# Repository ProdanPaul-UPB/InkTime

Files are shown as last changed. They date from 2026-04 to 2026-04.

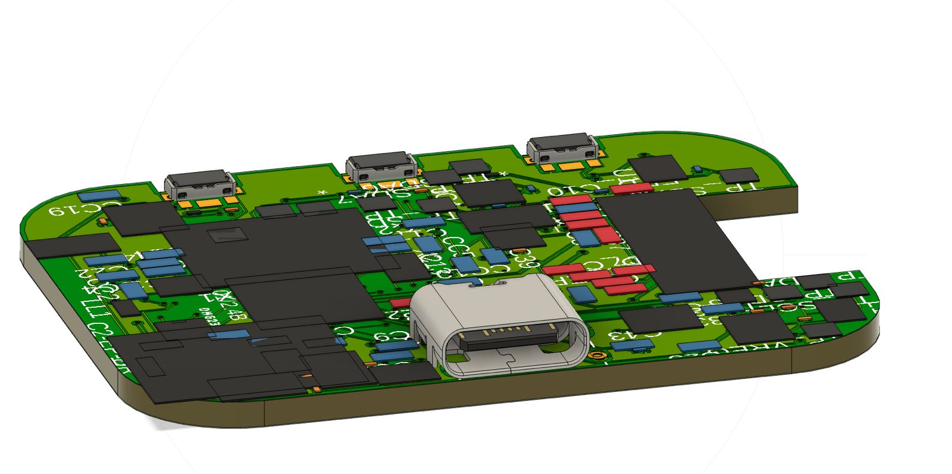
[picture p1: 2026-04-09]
Images/top_2.jpeg

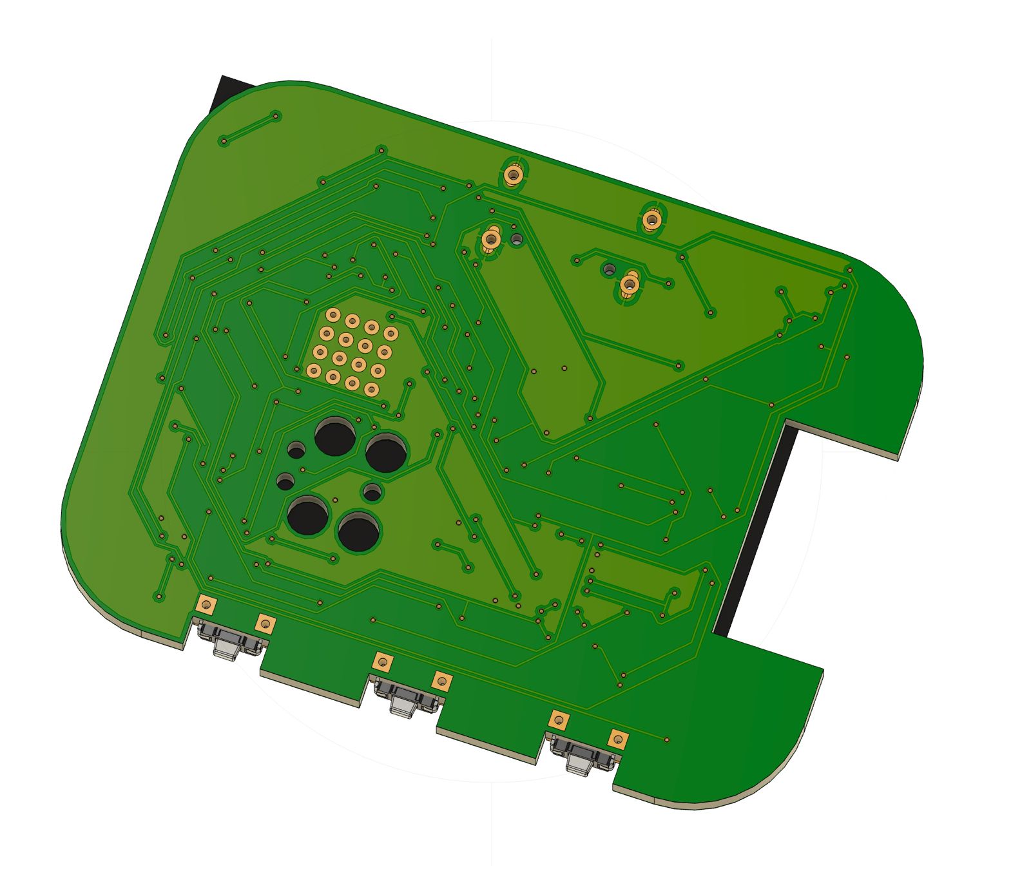
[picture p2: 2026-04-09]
Images/bottom.jpeg

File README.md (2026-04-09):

# InkTime — Open Source Smartwatch

InkTime is a low-power, open-source smartwatch built around the Nordic nRF52840 SoC and a 1.54" e-paper display. The goal was to design a device that can run for weeks on a single charge while still being useful as a daily wearable — no constant charging, no always-on backlight draining the battery.

This repo contains the full hardware design: schematic, PCB layout, manufacturing files, and the complete 3D assembly.

---

## Block Diagram

```
                        ┌─────────────────────────────────────────┐
                        │            nRF52840 (U1)                │
  USB-C (J4) ──► ESD ──►│ USB D+/D-          SPI ──────────────► │──► EPD Display (J1)
       │        (D3)    │                                         │    (Waveshare 1.54")
       │                │ I2C ──────────────────────────────────► │──► BMA423 IMU (IC3)
       ▼                │                   ├──────────────────► │──► MAX17048 Fuel Gauge (U3)
  BQ25180 (IC1) ───────►│ VBUS sense         └──────────────────► │──► DRV2605 Haptic (IC2)
  LiPo Charger          │                                         │
       │                │ GPIO ──────────────────────────────────►│──► SW_UP / SW_ENT / SW_DN
       ▼                │                                         │
  AKYGA LP502030        │ RF ────────────────────────────────────►│──► Matching Network
  3.7V / 250mAh         │                                         │    └──► ANT1 (2.4GHz)
       │                │ SWD ───────────────────────────────────►│──► TC2030-IDC (J2)
       ▼                └─────────────────────────────────────────┘
  RT6160A (IC9)
  DC-DC → 3.3V ──────────────────────────────────────────────────► All 3.3V rails
```

---

## Bill of Materials

| Ref | Component | Value / Part | Package | Datasheet | JLC Parts |
|-----|---|---|---|---|---|
| U1 | Nordic nRF52840 | nRF52840-QIAA | QFN-73 | [Datasheet](https://infocenter.nordicsemi.com/pdf/nRF52840_PS_v1.7.pdf) | [JLC](https://jlcpcb.com/partdetail/NordicSemiconductor-nRF52840QIAA/C190794) |
| IC1 | TI BQ25180 | LiPo Charger | DSBGA-9 | [Datasheet](https://www.ti.com/lit/ds/symlink/bq25180.pdf) | [JLC](https://jlcpcb.com/parts/componentSearch?searchTxt=BQ25180) |
| IC9 | RT6160A | DC-DC Buck 3.3V | WSON-6 | [Datasheet](https://www.richtek.com/assets/product_file/RT6160A/DS6160A-00.pdf) | [JLC](https://jlcpcb.com/parts/componentSearch?searchTxt=RT6160A) |
| U3 | MAX17048G+T10 | Fuel Gauge | SOT-23-6 | [Datasheet](https://www.analog.com/media/en/technical-documentation/data-sheets/MAX17048-MAX17049.pdf) | [JLC](https://jlcpcb.com/parts/componentSearch?searchTxt=MAX17048) |
| IC3 | BMA423 | Accelerometer | LGA-12 | [Datasheet](https://www.bosch-sensortec.com/media/boschsensortec/downloads/datasheets/bst-bma423-ds000.pdf) | [JLC](https://jlcpcb.com/parts/componentSearch?searchTxt=BMA423) |
| IC2 | DRV2605YZFR | Haptic Driver | DSBGA-12 | [Datasheet](https://www.ti.com/lit/ds/symlink/drv2605.pdf) | [JLC](https://jlcpcb.com/parts/componentSearch?searchTxt=DRV2605) |
| D3 | USBLC6-2SC6Y | USB ESD | SOT-363 | [Datasheet](https://www.st.com/resource/en/datasheet/usblc6-2.pdf) | [JLC](https://jlcpcb.com/parts/componentSearch?searchTxt=USBLC6-2SC6Y) |
| J4 | KH-TYPE-C-16P | USB-C Receptacle | SMD | — | [JLC](https://jlcpcb.com/parts/componentSearch?searchTxt=TYPE-C-16P) |
| J1 | Molex 503480-2400 | 24-pin FPC | SMD | [Datasheet](https://www.molex.com/en-us/products/part-detail/503480-2400) | [JLC](https://jlcpcb.com/parts/componentSearch?searchTxt=503480-2400) |
| J2 | TC2030-IDC | SWD Connector | THT | [Datasheet](https://www.tag-connect.com/product/tc2030-idc-nl) | — |
| ANT1 | 2450AT18B100E | 2.4GHz Antenna | SMD | [Datasheet](https://www.johansontechnology.com/datasheets/2450AT18B100E/2450AT18B100E.pdf) | [JLC](https://jlcpcb.com/parts/componentSearch?searchTxt=2450AT18B100E) |
| X1 | 32MHz Crystal | HFXO | SMD | — | [JLC](https://jlcpcb.com/parts/componentSearch?searchTxt=32MHz+crystal) |
| X2 | 32.768kHz Crystal | LFXO | SMD | — | [JLC](https://jlcpcb.com/parts/componentSearch?searchTxt=32.768kHz+crystal) |
| SW1-3 | EVP-AKE31A | Tactile Button | SMD | [Datasheet](https://industrial.panasonic.com/cdbs/www-data/pdf/ATV0000/ATV0000CE5.pdf) | [JLC](https://jlcpcb.com/parts/componentSearch?searchTxt=EVP-AKE31A) |
| — | AKYGA LP502030 | 3.7V / 250mAh LiPo | — | [Datasheet](https://www.tme.eu/Document/b9e12bf26ad0ba929a22ab5d58f022cd/AKY0106.pdf) | External |
| — | Waveshare WSH-12561 | 1.54" EPD Display | FPC-24 | [Datasheet](https://www.tme.eu/Document/0ca57a8ffbcd57b5bca53252eb9d6ec3/WSH-12561.pdf) | External |
| — | DFRobot FIT0774 | Vibration Motor | Coin 10×2.7mm | [Product page](https://www.tme.eu/ro/details/df-fit0774/motoare-dc/dfrobot/fit0774/) | External |
| Q3 | DMG2305UX | P-MOSFET | SOT-523 | [Datasheet](https://www.diodes.com/assets/Datasheets/DMG2305UX.pdf) | [JLC](https://jlcpcb.com/parts/componentSearch?searchTxt=DMG2305UX) |
| Q4 | SI1308EDL | N-MOSFET | SC-70 | [Datasheet](https://www.vishay.com/docs/73217/si1308edl.pdf) | [JLC](https://jlcpcb.com/parts/componentSearch?searchTxt=SI1308EDL) |
| L5 | 68µH Inductor | EPD Boost | 0402 | — | [JLC](https://jlcpcb.com/parts/componentSearch?searchTxt=68uH+0402) |
| L1 | 3.9nH Inductor | RF Matching | 0402 | — | [JLC](https://jlcpcb.com/parts/componentSearch?searchTxt=3.9nH+0402) |
| L2 | 15nH Inductor | RF Matching | 0402 | — | [JLC](https://jlcpcb.com/parts/componentSearch?searchTxt=15nH+0402) |
| L7 | 4.7µH Inductor | DC-DC Switching | 0402 | — | [JLC](https://jlcpcb.com/parts/componentSearch?searchTxt=4.7uH+0402) |
| R9 | 10kΩ | TS/MR Pull-down | 0201 | — | [JLC](https://jlcpcb.com/parts/componentSearch?searchTxt=10k+0201) |
| Various C | 100nF / 1µF / 10µF / 22µF | Decoupling | 0201 / 0402 | — | [JLC](https://jlcpcb.com/parts/componentSearch?searchTxt=100nF+0201) |

---

## Hardware Description

### Power Path

Power enters through the USB-C connector (J4). The BQ25180 charger (IC1) handles incoming VBUS and takes care of charging the LiPo battery safely — it supports up to 1A charge current with I²C-configurable parameters. The RT6160A (IC9) is a synchronous buck DC-DC converter that takes the battery voltage (3.0–4.2V) and steps it down to a clean 3.3V rail used by everything else on the board. The MAX17048 fuel gauge (U3) sits on the I²C bus and reports state of charge to the MCU so the watch can display battery percentage without the MCU having to do any ADC math itself.

The battery (AKYGA LP502030) is soldered directly to two test pads on the board rather than using a JST connector — this saves ~2mm of vertical height which matters a lot inside a watch case.

### Microcontroller

The nRF52840 (U1) is the brain of the device. It's a Cortex-M4F running at 64MHz with built-in Bluetooth 5.0 and a hardware USB controller. We used the QFN-73 package which has a 5×5mm exposed thermal pad underneath — there are thermal vias going through to the bottom GND plane to help with heat dissipation. The chip runs off the 3.3V rail and has 13 decoupling capacitors placed in a ring around its pads, as close to the power pins as the 2.54mm grid allows.

### Display Interface

The 1.54" e-paper display (Waveshare WSH-12561) connects through a 24-pin FPC connector (J1, Molex 503480-2400) on the left edge of the board. The EPD uses a 4-wire SPI interface plus three control lines (DC, RST, BUSY). The display only draws current during refresh — in static mode it consumes essentially nothing, which is the main reason e-paper was chosen for a watch that's supposed to last weeks.

Driving an EPD requires specific voltages that 3.3V alone can't provide. The EPD drive circuit uses a boost converter (Q4 N-MOSFET + L5 68µH inductor + D2 Schottky rectifier) to generate the higher voltages the display panel needs for VCOM and VDD. Q3 is a P-MOSFET power switch that the MCU uses to completely cut power to the display when it doesn't need it.

### Inertial Measurement Unit

The BMA423 (IC3) is a 6-axis IMU that handles step counting, activity recognition, and wrist-tilt detection (to wake the display when the user raises their wrist). It communicates over I²C and has its own interrupt output connected to a GPIO on the nRF52840 so it can wake the MCU from deep sleep without the MCU polling.

### Haptic Feedback

The DRV2605 (IC2) is a haptic driver that can drive both ERM (eccentric rotating mass) and LRA (linear resonant actuator) motors. It connects over I²C and has a library of pre-programmed waveforms built into its ROM, so the MCU just writes an effect number and the chip handles the timing. The FIT0774 vibration motor is a 10×2.7mm coin ERM motor that sits in the corner of the case behind the PCB.

### Bluetooth / RF

The nRF52840's built-in 2.4GHz radio connects to a chip antenna (Johanson 2450AT18B100E) through a pi-type matching network made of two series inductors (L1 3.9nH, L2 15nH) and two shunt capacitors (C3, C5 each 1pF). The antenna is placed at the edge of the PCB with a keepout zone below it — no copper planes or signal traces run under the antenna. Via stitching connects the top and bottom GND planes around the RF area to prevent ground loops from affecting the antenna's radiation pattern.

### USB and ESD Protection

The USBLC6-2SC6Y (D3) is a dual-channel TVS diode array placed between the USB-C connector and the nRF52840's USB pins. It clamps any ESD spikes from the connector before they can reach the MCU. The two CC pull-down resistors (5.1kΩ each) on CC1 and CC2 tell the USB host that this is a UFP (upstream facing port) device drawing up to 500mA.

### Debug Interface

The TC2030-IDC (J2) is a Tag-Connect 2×5 pogo-pin footprint for SWD debugging. It brings out SWDIO, SWDCLK, SWO, and RESET so a J-Link or similar debugger can program and debug the nRF52840 without needing a soldered header. Several test pads scattered around the board (labeled in silkscreen) expose the main power rails and I²C/SPI signals for probing during bring-up.

---

## nRF52840 Pin Mapping

| Pin | Signal | Connected To | Notes |
|-----|---|---|---|
| P0.06 | SDA | BMA423, MAX17048, DRV2605, BQ25180 | Shared I²C data |
| P0.08 | SCL | BMA423, MAX17048, DRV2605, BQ25180 | Shared I²C clock |
| P0.11 | MOSI | EPD Display (J1) | SPI data to display |
| P0.12 | MISO | EPD Display (J1) | SPI data from display |
| P0.13 | SCK | EPD Display (J1) | SPI clock |
| P0.14 | CS_EPD | EPD Display (J1) | SPI chip select |
| P0.15 | DC_EPD | EPD Display (J1) | Data/Command select |
| P0.16 | RST_EPD | EPD Display (J1) | Display reset |
| P0.17 | BUSY_EPD | EPD Display (J1) | Display busy indicator |
| P0.02 | SW_UP | SW1 (Up button) | Active low, internal pull-up |
| P0.03 | SW_ENT | SW2 (Enter button) | Active low, internal pull-up |
| P0.04 | SW_DN | SW3 (Down button) | Active low, internal pull-up |
| P0.29 | INT_IMU | BMA423 (IC3) | Interrupt from IMU |
| P0.30 | EN_EPD | Q3 gate | EPD power switch enable |
| P0.31 | EN_HAP | DRV2605 IN/TRIG | Haptic trigger signal |
| P0.20 | D+ | USBLC6 → USB-C | USB data positive |
| P0.22 | D− | USBLC6 → USB-C | USB data negative |
| SWDIO | SWDIO | TC2030-IDC (J2) | SWD debug interface |
| SWDCLK | SWDCLK | TC2030-IDC (J2) | SWD debug clock |
| P0.18 | RESET | TC2030-IDC (J2) | Hardware reset |
| XC1/XC2 | HFXO | X1 (32MHz) | High-frequency crystal oscillator |
| XL1/XL2 | LFXO | X2 (32.768kHz) | Low-frequency crystal for RTC |

The I²C bus is shared between four ICs — the BMA423, MAX17048, DRV2605, and BQ25180. Each has a different I²C address so there are no conflicts. SCL runs at 400kHz (fast mode).

---

## Power Consumption (estimated)

| Mode | Current draw |
|---|---|
| Deep sleep (display static, BLE off) | ~10–15 µA |
| Active (BLE advertising, IMU polling) | ~3–5 mA |
| Display refresh (EPD update) | ~20–30 mA for ~2s |
| USB charging | up to 250mA (BQ25180 configured) |

With the 250mAh battery and an estimated average current of ~0.5mA (mostly in deep sleep, occasional display updates and BLE), the target runtime is around 3–4 weeks between charges.

---

## PCB Details

- **Board dimensions:** 45.72mm × 34.29mm
- **Layers:** 2 (Top + Bottom)
- **Thickness:** 1.0mm
- **Surface finish:** HASL or ENIG
- **Min trace width:** 0.15mm (signals), 0.3mm (power)
- **Via drill:** 0.3mm min
- **GND planes:** Both TOP and BOTTOM layers, connected via stitching vias
- **Stackup:** Signal + GND pour (TOP) / GND pour + Signal (BOTTOM)
- **Antenna keepout:** No copper or signals under ANT1

All components are on the TOP layer only.

---

## Known Issues and Design Decisions

- **Board outline clearance errors:** The three tactile buttons (SW1–SW3) and the USB-C connector are intentionally positioned so they protrude into the board edge clearance zone. This is by design — they need to align with cutouts in the physical case and this placement was confirmed in the reference `.fbrd` layout from the course. These DRC errors are accepted and documented here.

- **Drill size errors:** Some via drill sizes fall slightly below the JLCPCB minimum due to the dense BGA escape routing under U1. These were the smallest vias needed to escape the MCU pads while still leaving clearance for adjacent traces. A PCB house that supports 0.2mm drills (like PCBWay) can manufacture these without issue. For JLCPCB specifically, these can be bumped to 0.3mm at the cost of routing one or two signals to alternate paths.

- **Battery connection:** The battery is soldered directly to TP_VBAT and TP_GND test pads instead of using the JST connector. This was intentional to reduce the height of the assembly so it fits inside the 1.0mm-thick PCB + battery stack constraint of the inktime_case enclosure.

- **EPD drive circuit:** The boost converter was designed around the voltage requirements in the WSH-12561 datasheet. The VCOM voltage is set via SJ1 — the solder jumper selects between direct GND and a resistor-divided reference, allowing adjustment during bring-up if the display contrast isn't right with the default value.

---

## Repository Structure

```
Hardware/
├── inktime.sch          — Schematic (Fusion 360 / EAGLE format)
├── inktime.brd          — PCB board file
└── inktime_schematic.pdf
Manufacturing/
├── gerbers.zip
├── inktime.bom
└── inktime.cpl
Mechanical/
├── inktime_assembly_exploded.step
└── inktime_complete.f3z
Images/
└── (PCB renders and assembly photos)
LICENSE
README.md
```

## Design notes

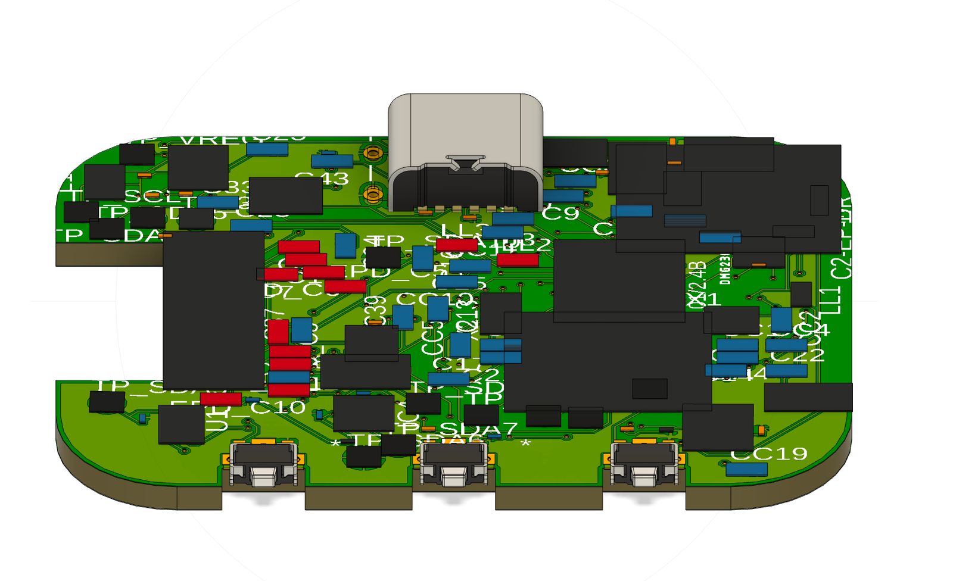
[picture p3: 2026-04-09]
Images/top_1.jpeg

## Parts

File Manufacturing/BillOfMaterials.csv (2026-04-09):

Qty | Value | Device | Package | Parts | Description | ARROW_PART_NUMBER | ARROW_PRICE-STOCK | AVAILABILITY | CHECK_PRICES | COPYRIGHT | DESCRIPTION | DIGI-KEY_PART_NUMBER_1 | DIGI-KEY_PART_NUMBER_2 | DIGI-KEY_PART_NUMBER_3 | HEIGHT | JLCPCB | MANUFACTURER_NAME | MANUFACTURER_PART_NUMBER | MF | MOUSER_PART_NUMBER | MOUSER_PRICE-STOCK | MP | PACKAGE | POPULARITY | PRICE | PURCHASE-URL | SNAPEDA_LINK | SPICEMODEL | SPICEPREFIX | TP_SIGNAL_NAME
1 | 0 | ESP32_C6_LIBRARY_7_JUMPER_SJ | ESP32_C6_LIBRARY_7_JUMPER_SJ | SJ1 | SMD solder JUMPER |  |  |  |  |  |  |  |  |  |  |  |  |  |  |  |  |  |  | 3
1 | 0.1uF | GRM011R60J152KE01L_1_GRM011R60J152KE01L | GRM011R60J152KE01L_1_0201 | C4 | Check availability
1 | 0.1uF | NORDIC_NRF_3_CAPACITOR_0402_M | NORDIC_NRF_3_RESC0402_M | C23 | Generic chip capacitor
1 | 0.1uF/50V | NORDIC_NRF_3_CAPACITOR_0402_M | NORDIC_NRF_3_RESC0402_M | EPD_C5 | Generic chip capacitor
4 | 100nF | NORDIC_NRF_3_CAPACITOR_0402_M | NORDIC_NRF_3_RESC0402_M | C7, C8, CC5, CC19 | Generic chip capacitor
2 | 100pF | NORDIC_NRF_3_CAPACITOR_0402_M | NORDIC_NRF_3_RESC0402_M | C12, CC11 | Generic chip capacitor
1 | 10K | CPF0201D7K68C1_CPF0201D7K68C1 | CPF0201D7K68C1_0201 | R9 | 7.68k 0201 Thin Film Surface Mount Fixed Resistor +/-0.5% 0.031W CPF0201D7K68C1
3 | 10uF | NORDIC_NRF_3_CAPACITOR_0402_M | NORDIC_NRF_3_RESC0402_M | C1-EP-DR, C24, C39 | Generic chip capacitor
1 | 10uH | NORDIC_NRF_2_INDUCTOR_0402_M | NORDIC_NRF_2_RESC0402_M | LL2 | Generic chip inductor
4 | 12pF | NORDIC_NRF_3_CAPACITOR_0402_M | NORDIC_NRF_3_RESC0402_M | C17, C18, CC1, CC2 | Generic chip capacitor
1 | 15uH | NORDIC_NRF_2_INDUCTOR_0402_M | NORDIC_NRF_2_RESC0402_M | LL3 | Generic chip inductor
2 | 1pF | NORDIC_NRF_3_CAPACITOR_0402_M | NORDIC_NRF_3_RESC0402_M | CC3, CC4 | Generic chip capacitor
1 | 1uF | GRM011R60J152KE01L_1_GRM011R60J152KE01L | GRM011R60J152KE01L_1_0201 | C3 | Check availability
3 | 1uF | NORDIC_NRF_3_CAPACITOR_0402_M | NORDIC_NRF_3_RESC0402_M | C15, C37, C38 | Generic chip capacitor
9 | 1uF/50V | NORDIC_NRF_3_CAPACITOR_0402_M | NORDIC_NRF_3_RESC0402_M | EPD_C1, EPD_C2, EPD_C6, EPD_C7, EPD_C8, EPD_C9, EPD_C10, EPD_C11, EPD_C12 | Generic chip capacitor
3 | 2025-10-22_07-23-44_LIBRARY_EVP-AKE31ASW_EVP-AKE31A_PAN | 2025-10-22_07-23-44_LIBRARY_EVP-AKE31ASW_EVP-AKE31A_PAN | 2025-10-22_07-23-44_LIBRARY_SW_EVP-AKE31A_PAN | SW1, SW2, SW3 |  |  |  |  |  | Copyright (C) 2025 Ultra Librarian. All rights reserved. |  | P123437TR-ND | P123437CT-ND | P123437DKR-ND |  |  | Panasonic | EVP-AKE31A
2 | 22uF | NORDIC_NRF_3_CAPACITOR_0402_M | NORDIC_NRF_3_RESC0402_M | C25, C33 | Generic chip capacitor
1 | 2450AT18B100E_2450AT18B100E | 2450AT18B100E_2450AT18B100E | 2450AT18B100E_ANTC3216X140N | ANT1 | Antennas 2.45GHz ANTENNA | 2450AT18B100E | https://www.arrow.com/en/products/2450at18b100e/johanson-dielectrics?utm_currency=USD&region=nac |  |  |  | Antennas 2.45GHz ANTENNA |  |  |  | 1.4mm |  | JOHANSON TECHNOLOGY | 2450AT18B100E |  | 609-2450AT18B100E | https://www.mouser.co.uk/ProductDetail/Johanson-Technology/2450AT18B100E?qs=yCnrNFeXz%252Bh5MFsFIXGZGA%3D%3D
1 | 3.9nH | NORDIC_NRF_2_INDUCTOR_0402_M | NORDIC_NRF_2_RESC0402_M | LL1 | Generic chip inductor
1 | 32.768KHz | NORDIC_NRF_1_XTAL_32KHZ | NORDIC_NRF_1_XTAL_3215_N | X2
1 | 32MHz | NORDIC_NRF_XTAL_32MHZ | NORDIC_NRF_BT-XTAL_2016_N | X1
5 | 4.7uF | NORDIC_NRF_3_CAPACITOR_0402_M | NORDIC_NRF_3_RESC0402_M | C6, C20, C21, C43, CC14 | Generic chip capacitor
1 | 4.7uF/25V | ESP32_C6_LIBRARY_1_ESP32_WROVER_EAGLE-LTSPICE_CC0402 | ESP32_C6_LIBRARY_1_ESP32_WROVER_EAGLE-LTSPICE_C0402 | C2-EP-DR | CAPACITOR, European symbol |  |  |  |  |  |  |  |  |  |  |  |  |  |  |  |  |  |  |  |  |  |  | NONE | C
1 | 47nF | NORDIC_NRF_3_CAPACITOR_0402_M | NORDIC_NRF_3_RESC0402_M | C16 | Generic chip capacitor
1 | 503480-2400_503480-2400 | 503480-2400_503480-2400 | 503480-2400_5034802400 | J2 | FFC & FPC Connectors 0.5mm FPC RA SMT Dual Contact 24Ckt |  |  |  |  |  | FFC & FPC Connectors 0.5mm FPC RA SMT Dual Contact 24Ckt |  |  |  | 1.87mm |  | Molex | 503480-2400 |  | 538-503480-2400 | https://www.mouser.co.uk/ProductDetail/Molex/503480-2400?qs=OAhjpuo3Vu7efIoxFh9AOw%3D%3D
1 | 820pF | NORDIC_NRF_3_CAPACITOR_0402_M | NORDIC_NRF_3_RESC0402_M | C9 | Generic chip capacitor
1 | BMA423_BMA423 | BMA423_BMA423 | BMA423_BMA423 | IC3 | Accelerometers Triaxial low-g 12bit Acceleration Sensor | BMA423 | https://www.arrow.com/en/products/bma423/bosch |  |  |  | Accelerometers Triaxial low-g 12bit Acceleration Sensor |  |  |  | 1mm |  | BOSCH | BMA423 |  | 262-BMA423 | https://www.mouser.co.uk/ProductDetail/Bosch-Sensortec/BMA423?qs=HXFqYaX1Q2xC%252BSgeGoX3mg%3D%3D
1 | BQ25180YBGR_BQ25180YBGR | BQ25180YBGR_BQ25180YBGR | BQ25180YBGR_BGA8C40P2X4_100X155X50 | IC1 | Charger IC Lithium Ion/Polymer, Lithium Iron Phosphate 8-DSBGA (1.6x1.1) | BQ25180YBGR | https://www.arrow.com/en/products/bq25180ybgr/texas-instruments?utm_currency=USD&region=nac |  |  |  | Charger IC Lithium Ion/Polymer | Lithium Iron Phosphate 8-DSBGA (1.6x1.1) |  |  |  | 0.5mm |  | Texas Instruments | BQ25180YBGR |  | 595-BQ25180YBGR | https://www.mouser.co.uk/ProductDetail/Texas-Instruments/BQ25180YBGR?qs=doiCPypUmgEWjAK%252BJAX6Tw%3D%3D
10 | CPF0201D7K68C1_CPF0201D7K68C1 | CPF0201D7K68C1_CPF0201D7K68C1 | CPF0201D7K68C1_0201 | R2, R3, R4, R5, R8, R11, R12, R13, R14, R15 | 7.68k 0201 Thin Film Surface Mount Fixed Resistor +/-0.5% 0.031W CPF0201D7K68C1
1 | DRV2605YZFR_DRV2605YZFR | DRV2605YZFR_DRV2605YZFR | DRV2605YZFR_BGA9C50P3X3_144X144X62 | IC4 | Haptic Driver for ERM/LRA with Built-In Library and Smart Loop Architecture | DRV2605YZFR | https://www.arrow.com/en/products/drv2605yzfr/texas-instruments?region=nac |  |  |  | Haptic Driver for ERM/LRA with Built-In Library and Smart Loop Architecture |  |  |  | 0.625mm |  | Texas Instruments | DRV2605YZFR
1 | ESP32_C6_LIBRARY_3_USBLC6-2SC6Y | ESP32_C6_LIBRARY_3_USBLC6-2SC6Y | ESP32_C6_LIBRARY_3_SOT95P280X145-6N | D4 | Low Cap. ESD Protection Auto SOT-23-6 STMicroelectronics USBLC6-2SC6Y, Dual Uni-Directional TVS Diode Array, 6-Pin SOT-23 |  |  | In Stock | https://www.snapeda.com/parts/USBLC6-2SC6Y/STMicroelectronics/view-part/?ref=eda |  | 17V Clamp 5A (8/20µs) Ipp Tvs Diode Surface Mount SOT-23-6 |  |  |  |  |  |  |  | STMicroelectronics |  |  | USBLC6-2SC6Y | SOT-23-6 STMicroelectronics |  | None |  | https://www.snapeda.com/parts/USBLC6-2SC6Y/STMicroelectronics/view-part/?ref=snap
3 | ESP32_C6_LIBRARY_5_MBR0530 | ESP32_C6_LIBRARY_5_MBR0530 | ESP32_C6_LIBRARY_5_SOD3716X135N | D1, D2, D3 | ON SEMICONDUCTOR - MBR0530 - DIODE, SCHOTTKY, 0.5A, 30V, SOD-123 |  |  | In Stock | https://www.snapeda.com/parts/MBR0530/Onsemi/view-part/?ref=eda |  | Diode Schottky 30 V 500mA Surface Mount SOD-123 |  |  |  |  |  |  |  | ON Semiconductor |  |  | MBR0530 | SOD-123-2 ON Semiconductor |  | None | https://www.snapeda.com/api/url_track_click_mouser/?unipart_id=179458&manufacturer=ON Semiconductor&part_name=MBR0530&search_term=None | https://www.snapeda.com/parts/MBR0530/Onsemi/view-part/?ref=snap
1 | ESP32_C6_LIBRARY_6_SI1308EDL-T1-GE3 | ESP32_C6_LIBRARY_6_SI1308EDL-T1-GE3 | ESP32_C6_LIBRARY_6_SOT65P210X110-3N | Q2 | MOSFET N-Ch 30V 1.5A TrenchFET SC70 Vishay Si1308EDL-T1-GE3 N-channel MOSFET Transistor, 1.5 A, 30 V, 3-Pin SC-70 |  |  | In Stock | https://www.snapeda.com/parts/SI1308EDL-T1-GE3/Vishay+Siliconix/view-part/?ref=eda |  | Si1308EDL-T1-GE3 N-channel MOSFET Transistor | 1.5 A | 30 V | 3-Pin SC-70 | Siliconix / Vishay SI1308EDL-T1-GE3 |  |  |  |  |  |  |  | Vishay Siliconix |  |  | SI1308EDL-T1-GE3 | SOT-323 Vishay Semiconductor |  | None | https://www.snapeda.com/api/url_track_click_mouser/?unipart_id=274603&manufacturer=Vishay Siliconix&part_name=SI1308EDL-T1-GE3&search_term=None | https://www.snapeda.com/parts/SI1308EDL-T1-GE3/Vishay+Siliconix/view-part/?ref=snap
1 | ESP32_C6_LIBRARY_MAX17048G+T10 | ESP32_C6_LIBRARY_MAX17048G+T10 | ESP32_C6_LIBRARY_SON50P200X200X80-9N | U1 | Check availability |  |  | In Stock | https://www.snapeda.com/parts/MAX17048G+T10/Analog+Devices/view-part/?ref=eda |  | 3µA 1-Cell/2-Cell Fuel Gauge with ModelGauge |  |  |  |  |  |  |  | Analog Devices |  |  | MAX17048G+T10 | TDFN-8 Maxim |  | None | https://www.snapeda.com/api/url_track_click_mouser/?unipart_id=329239&manufacturer=Analog Devices&part_name=MAX17048G+T10&search_term=None | https://www.snapeda.com/parts/MAX17048G+T10/Analog+Devices/view-part/?ref=snap
5 | GRM011R60J152KE01L_1_GRM011R60J152KE01L | GRM011R60J152KE01L_1_GRM011R60J152KE01L | GRM011R60J152KE01L_1_0201 | C2, C5, C10, C11, C42 | Check availability
14 | HECTOR_WATCH_1_TPTP20R | HECTOR_WATCH_1_TPTP20R | HECTOR_WATCH_1_TP20R | TP_3V3, TP_SCL, TP_SDA, TP_SDA1, TP_SDA2, TP_SDA3, TP_SDA4, TP_SDA5, TP_SDA6, TP_SDA7, TP_SDA8, TP_SDA9, TP_SDA10, TP_VREG | Test pad |  |  |  |  |  |  |  |  |  |  |  |  |  |  |  |  |  |  | 2
1 | KH-TYPE-C-16P_KH-TYPE-C-16P | KH-TYPE-C-16P_KH-TYPE-C-16P | KH-TYPE-C-16P_KINGHELM_KH-TYPE-C-16P | J3 | Check availability |  |  | Not in stock | https://www.snapeda.com/parts/KH-TYPE-C-16P/Kinghelm/view-part/?ref=eda |  |  |  |  |  |  |  |  |  | kinghelm |  |  | KH-TYPE-C-16P | None |  | None |  | https://www.snapeda.com/parts/KH-TYPE-C-16P/Kinghelm/view-part/?ref=snap
1 | MLP2016SR47MT0S1_FTC252012SR47MBCA | MLP2016SR47MT0S1_FTC252012SR47MBCA | MLP2016SR47MT0S1_INDC2016X100N | L1 | SMD / SMT Inductors (Coils), L=0.47?H, L x W x T : |  |  |  |  |  | SMD / SMT Inductors (Coils) | L=0.47?H | L x W x T : |  |  |  | 1mm | https://jlcpcb.com/partdetail/6763488-FTC252012SR47MBCA/C5832368 | TDK | FTC252012SR47MBCA
2 | N.C | NORDIC_NRF_3_CAPACITOR_0402_M | NORDIC_NRF_3_RESC0402_M | C13, CC10 | Generic chip capacitor
1 | NORDIC_NRF_4_NRF52840_QF | NORDIC_NRF_4_NRF52840_QF | NORDIC_NRF_4_AQFN50P700X700X85_HS-74N | P1.01/2.4B | nRF52840
1 | RT6160AWSC_RT6160AWSC | RT6160AWSC_RT6160AWSC | RT6160AWSC_BGA15C40P3X5_140X230X60 | IC2 | Buck-Boost Regulator Positive Output Step-Up/Step-Down I2C DC-DC Controller IC 15-WL-CSP (BSC) (1.4x2.3) |  |  |  |  |  | Buck-Boost Regulator Positive Output Step-Up/Step-Down I2C DC-DC Controller IC 15-WL-CSP (BSC) (1.4x2.3) |  |  |  | 0.6mm |  | RICHTEK | RT6160AWSC |  | 835-RT6160AWSC | https://www.mouser.co.uk/ProductDetail/Richtek/RT6160AWSC?qs=amGC7iS6iy%2FLd9PSoixZXQ%3D%3D

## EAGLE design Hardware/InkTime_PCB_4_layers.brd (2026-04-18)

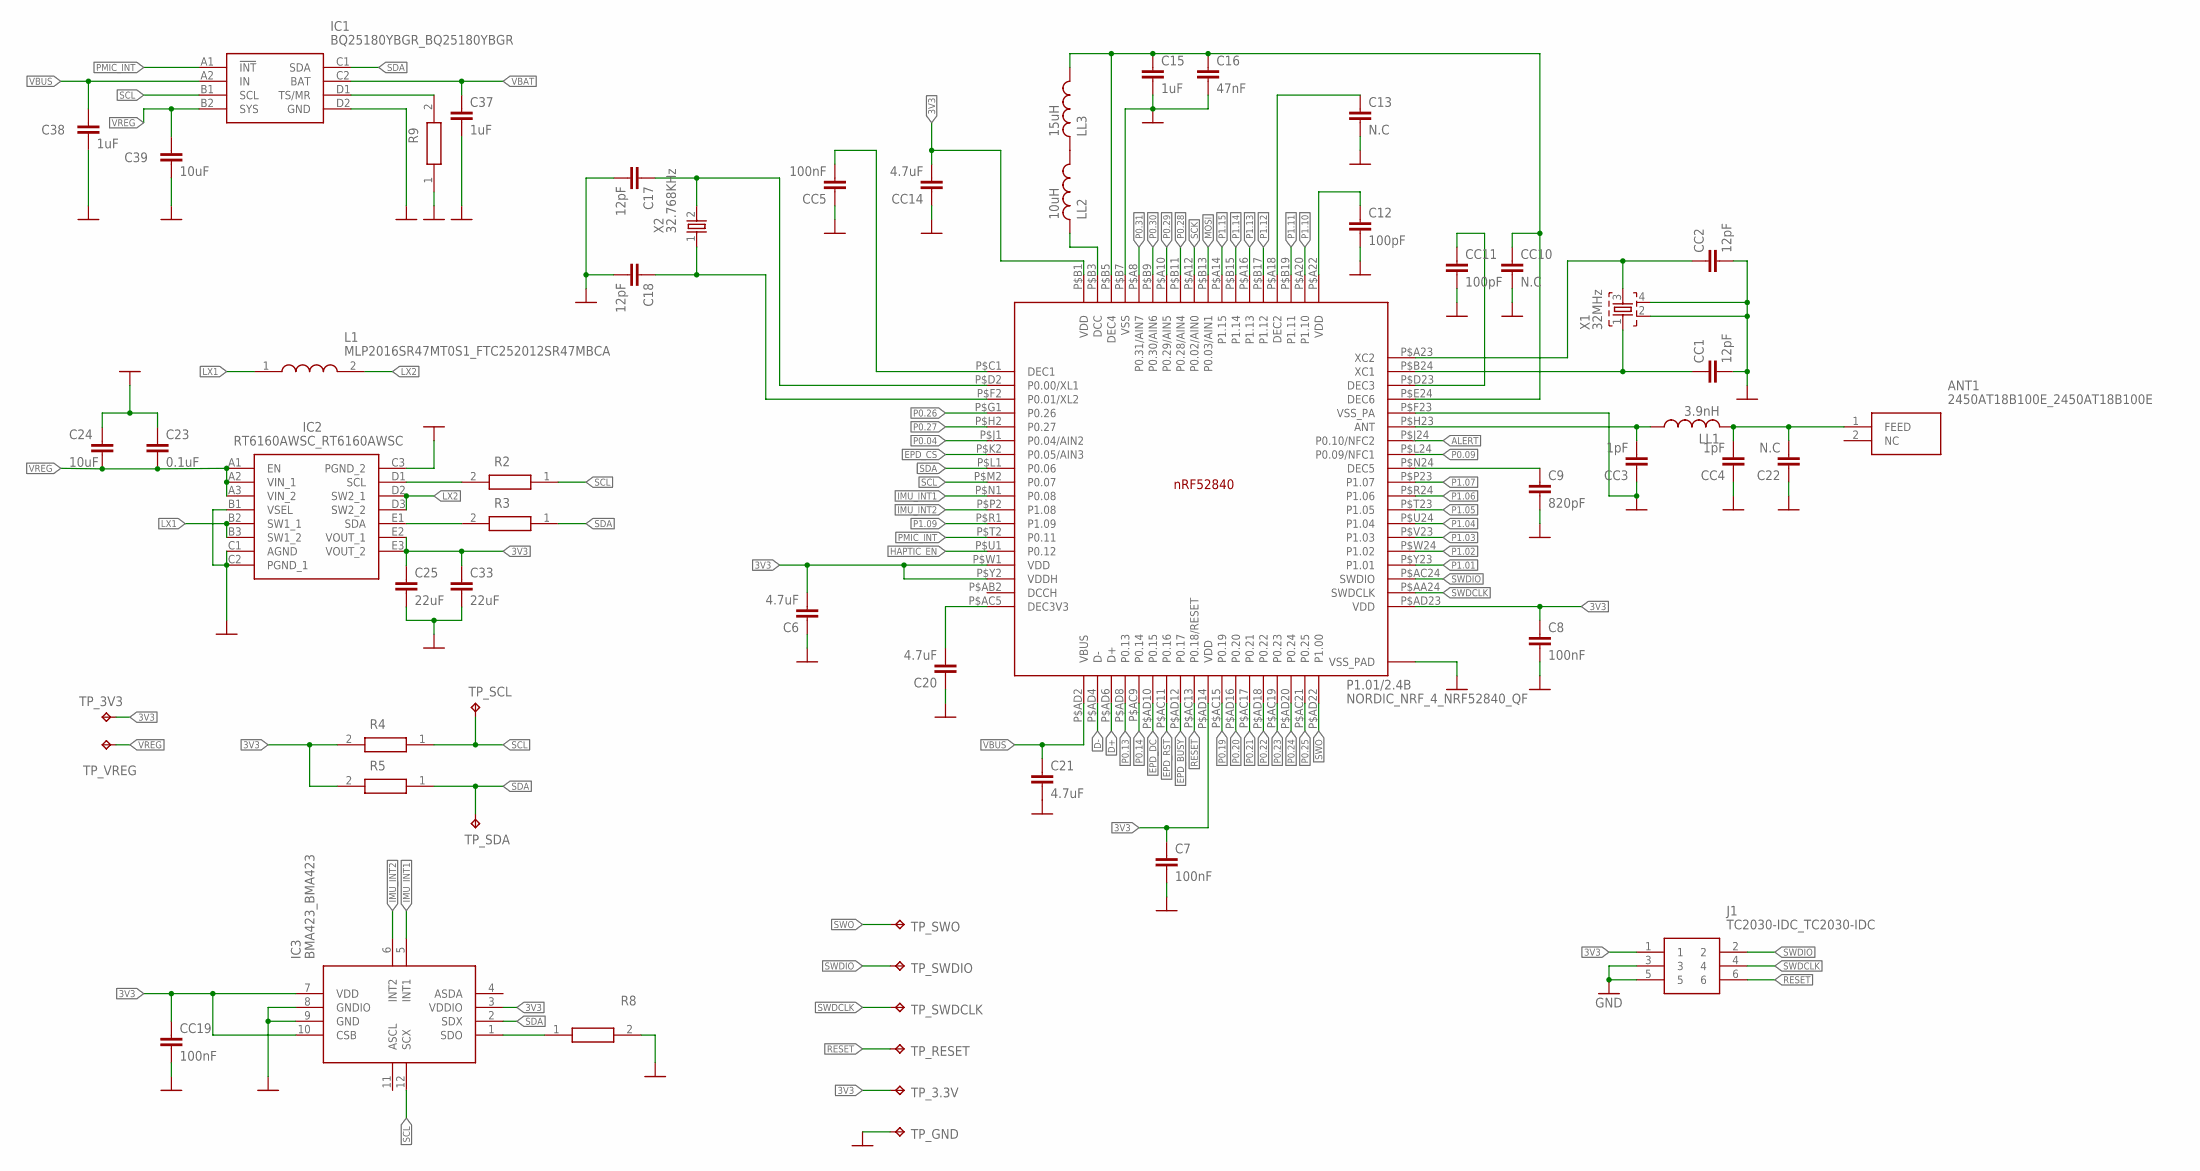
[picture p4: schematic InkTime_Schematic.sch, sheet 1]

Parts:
ANT1: 2450AT18B100E_2450AT18B100E; 2450AT18B100E_ANTC3216X140N
C6, C20, C21: 4.7uF; NORDIC_NRF_3_RESC0402_M
C7, C8: 100nF; NORDIC_NRF_3_RESC0402_M
C9: 820pF; NORDIC_NRF_3_RESC0402_M
C12: 100pF; NORDIC_NRF_3_RESC0402_M
C13, C22: N.C; NORDIC_NRF_3_RESC0402_M
C15, C37, C38: 1uF; NORDIC_NRF_3_RESC0402_M
C16: 47nF; NORDIC_NRF_3_RESC0402_M
C17, C18: 12pF; NORDIC_NRF_3_RESC0402_M
C23: 0.1uF; NORDIC_NRF_3_RESC0402_M
C24, C39: 10uF; NORDIC_NRF_3_RESC0402_M
C25, C33: 22uF; NORDIC_NRF_3_RESC0402_M
CC1, CC2: 12pF; NORDIC_NRF_3_RESC0402_M
CC3, CC4: 1pF; NORDIC_NRF_3_RESC0402_M
CC5, CC19: 100nF; NORDIC_NRF_3_RESC0402_M
CC10: N.C; NORDIC_NRF_3_RESC0402_M
CC11: 100pF; NORDIC_NRF_3_RESC0402_M
CC14: 4.7uF; NORDIC_NRF_3_RESC0402_M
IC1: BQ25180YBGR_BQ25180YBGR; BQ25180YBGR_BGA8C40P2X4_100X155X50
IC2: RT6160AWSC_RT6160AWSC; RT6160AWSC_BGA15C40P3X5_140X230X60
IC3: BMA423_BMA423
J1: TC2030-IDC_TC2030-IDC; TC2030-IDC_TC2030IDC
L1: MLP2016SR47MT0S1_FTC252012SR47MBCA; MLP2016SR47MT0S1_INDC2016X100N
LL1: 3.9nH; NORDIC_NRF_2_RESC0402_M
LL2: 10uH; NORDIC_NRF_2_RESC0402_M
LL3: 15uH; NORDIC_NRF_2_RESC0402_M
P1.01/2.4B: NORDIC_NRF_4_NRF52840_QF; NORDIC_NRF_4_AQFN50P700X700X85_HS-74N
R2, R3, R4, R5, R8: CPF0201D7K68C1_CPF0201D7K68C1; CPF0201D7K68C1_0201
R9: 10K; CPF0201D7K68C1_0201
TP_3.3V, TP_3V3: HECTOR_WATCH_1_TPTP20R; HECTOR_WATCH_1_TP20R
TP_GND: HECTOR_WATCH_1_TPTP20R; HECTOR_WATCH_1_TP20R
TP_RESET: HECTOR_WATCH_1_TPTP20R; HECTOR_WATCH_1_TP20R
TP_SCL: HECTOR_WATCH_1_TPTP20R; HECTOR_WATCH_1_TP20R
TP_SDA: HECTOR_WATCH_1_TPTP20R; HECTOR_WATCH_1_TP20R
TP_SWDCLK: HECTOR_WATCH_1_TPTP20R; HECTOR_WATCH_1_TP20R
TP_SWDIO: HECTOR_WATCH_1_TPTP20R; HECTOR_WATCH_1_TP20R
TP_SWO: HECTOR_WATCH_1_TPTP20R; HECTOR_WATCH_1_TP20R
TP_VREG: HECTOR_WATCH_1_TPTP20R; HECTOR_WATCH_1_TP20R
X1: 32MHz; NORDIC_NRF_BT-XTAL_2016_N
X2: 32.768KHz; NORDIC_NRF_1_XTAL_3215_N

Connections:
3V3: C6.2, C7.1, C8.1, C25.1, C33.1, CC14.2, CC19.1, IC2.E2 (VOUT_1), IC2.E3 (VOUT_2), IC3.3 (VDDIO), IC3.7 (VDD), IC3.10 (CSB), J1.1, P1.01/2.4B.P$AD14 (VDD), P1.01/2.4B.P$AD23 (VDD), P1.01/2.4B.P$B1 (VDD), P1.01/2.4B.P$W1 (VDD), P1.01/2.4B.P$Y2 (VDDH), R4.2, R5.2, TP_3.3V.TP, TP_3V3.TP; also elsewhere on the board
ALERT: P1.01/2.4B.P$J24 (P0.10/NFC2); also elsewhere on the board
D+: P1.01/2.4B.P$AD6 (D+); also elsewhere on the board
D-: P1.01/2.4B.P$AD4 (D-); also elsewhere on the board
EPD_BUSY: P1.01/2.4B.P$AD12 (P0.17); also elsewhere on the board
EPD_CS: P1.01/2.4B.P$K2 (P0.05/AIN3); also elsewhere on the board
EPD_DC: P1.01/2.4B.P$AD10 (P0.15); also elsewhere on the board
EPD_RST: P1.01/2.4B.P$AC11 (P0.16); also elsewhere on the board
GND: C6.1, C7.2, C8.2, C9.2, C12.2, C13.2, C15.2, C16.2, C17.2, C18.2, C20.1, C21.2, C22.1, C23.1, C24.1, C25.2, C33.2, C37.2, C38.2, C39.2, CC1.2, CC2.2, CC3.1, CC4.1, CC5.1, CC10.2, CC11.2, CC14.1, CC19.2, IC1.D2 (GND), IC2.B1 (VSEL), IC2.C1 (AGND), IC2.C2 (PGND_1), IC2.C3 (PGND_2), IC3.8 (GNDIO), IC3.9 (GND), J1.3, J1.5, P1.01/2.4B.P$74 (VSS_PAD), P1.01/2.4B.P$75 (VSS_PAD), P1.01/2.4B.P$76 (VSS_PAD), P1.01/2.4B.P$77 (VSS_PAD), P1.01/2.4B.P$78 (VSS_PAD), P1.01/2.4B.P$79 (VSS_PAD), P1.01/2.4B.P$80 (VSS_PAD), P1.01/2.4B.P$81 (VSS_PAD), P1.01/2.4B.P$82 (VSS_PAD), P1.01/2.4B.P$83 (VSS_PAD), P1.01/2.4B.P$84 (VSS_PAD), P1.01/2.4B.P$85 (VSS_PAD), P1.01/2.4B.P$86 (VSS_PAD), P1.01/2.4B.P$87 (VSS_PAD), P1.01/2.4B.P$88 (VSS_PAD), P1.01/2.4B.P$89 (VSS_PAD), P1.01/2.4B.P$90 (VSS_PAD), P1.01/2.4B.P$B7 (VSS), P1.01/2.4B.P$F23 (VSS_PA), R8.2, R9.1, TP_GND.TP, X1.2, X1.4; also elsewhere on the board
HAPTIC_EN: P1.01/2.4B.P$U1 (P0.12); also elsewhere on the board
IMU_INT1: IC3.5 (INT1), P1.01/2.4B.P$N1 (P0.08)
IMU_INT2: IC3.6 (INT2), P1.01/2.4B.P$P2 (P1.08)
LX1: IC2.B2 (SW1_1), IC2.B3 (SW1_2), L1.1
LX2: IC2.D2 (SW2_1), IC2.D3 (SW2_2), L1.2
MOSI: P1.01/2.4B.P$B13 (P0.03/AIN1); also elsewhere on the board
unnamed: IC1.D1 (TS/MR), R9.2
unnamed: C9.1, P1.01/2.4B.P$N24 (DEC5)
unnamed: CC3.2, LL1.1, P1.01/2.4B.P$H23 (ANT)
unnamed: IC2.D1 (SCL), R2.2
unnamed: IC2.E1 (SDA), R3.2
unnamed: C20.2, P1.01/2.4B.P$AC5 (DEC3V3)
unnamed: ANT1.1 (FEED), C22.2, CC4.2, LL1.2
unnamed: CC1.1, P1.01/2.4B.P$B24 (XC1), X1.1
unnamed: CC2.1, P1.01/2.4B.P$A23 (XC2), X1.3
unnamed: CC11.1, P1.01/2.4B.P$D23 (DEC3)
unnamed: C18.1, P1.01/2.4B.P$F2 (P0.01/XL2), X2.1
unnamed: C12.1, P1.01/2.4B.P$A22 (VDD)
unnamed: C13.1, P1.01/2.4B.P$A18 (DEC2)
unnamed: LL2.1, LL3.2
unnamed: LL2.2, P1.01/2.4B.P$B3 (DCC)
unnamed: C15.1, C16.1, CC10.1, LL3.1, P1.01/2.4B.P$B5 (DEC4), P1.01/2.4B.P$E24 (DEC6)
unnamed: C17.1, P1.01/2.4B.P$D2 (P0.00/XL1), X2.2
unnamed: IC3.1 (SDO), R8.1
unnamed: CC5.2, P1.01/2.4B.P$C1 (DEC1)
P0.04: P1.01/2.4B.P$J1 (P0.04/AIN2)
P0.09: P1.01/2.4B.P$L24 (P0.09/NFC1)
P0.13: P1.01/2.4B.P$AD8 (P0.13); also elsewhere on the board
P0.14: P1.01/2.4B.P$AC9 (P0.14); also elsewhere on the board
P0.19: P1.01/2.4B.P$AC15 (P0.19)
P0.20: P1.01/2.4B.P$AD16 (P0.20)
P0.21: P1.01/2.4B.P$AC17 (P0.21)
P0.22: P1.01/2.4B.P$AD18 (P0.22)
P0.23: P1.01/2.4B.P$AC19 (P0.23)
P0.24: P1.01/2.4B.P$AD20 (P0.24)
P0.25: P1.01/2.4B.P$AC21 (P0.25)
P0.26: P1.01/2.4B.P$G1 (P0.26)
P0.27: P1.01/2.4B.P$H2 (P0.27)
P0.28: P1.01/2.4B.P$B11 (P0.28/AIN4)
P0.29: P1.01/2.4B.P$A10 (P0.29/AIN5)
P0.30: P1.01/2.4B.P$B9 (P0.30/AIN6)
P0.31: P1.01/2.4B.P$A8 (P0.31/AIN7)
P1.01: P1.01/2.4B.P$Y23 (P1.01); also elsewhere on the board
P1.02: P1.01/2.4B.P$W24 (P1.02); also elsewhere on the board
P1.03: P1.01/2.4B.P$V23 (P1.03)
P1.04: P1.01/2.4B.P$U24 (P1.04)
P1.05: P1.01/2.4B.P$T23 (P1.05)
P1.06: P1.01/2.4B.P$R24 (P1.06)
P1.07: P1.01/2.4B.P$P23 (P1.07)
P1.09: P1.01/2.4B.P$R1 (P1.09)
P1.10: P1.01/2.4B.P$A20 (P1.10)
P1.11: P1.01/2.4B.P$B19 (P1.11)
P1.12: P1.01/2.4B.P$B17 (P1.12)
P1.13: P1.01/2.4B.P$A16 (P1.13)
P1.14: P1.01/2.4B.P$B15 (P1.14)
P1.15: P1.01/2.4B.P$A14 (P1.15)
PMIC_INT: IC1.A1 (!INT), P1.01/2.4B.P$T2 (P0.11)
RESET: J1.6, P1.01/2.4B.P$AC13 (P0.18/RESET), TP_RESET.TP
SCK: P1.01/2.4B.P$A12 (P0.02/AIN0); also elsewhere on the board
SCL: IC1.B1 (SCL), IC3.12 (SCX), P1.01/2.4B.P$M2 (P0.07), R2.1, R4.1, TP_SCL.TP; also elsewhere on the board
SDA: IC1.C1 (SDA), IC3.2 (SDX), P1.01/2.4B.P$L1 (P0.06), R3.1, R5.1, TP_SDA.TP; also elsewhere on the board
SWDCLK: J1.4, P1.01/2.4B.P$AA24 (SWDCLK), TP_SWDCLK.TP
SWDIO: J1.2, P1.01/2.4B.P$AC24 (SWDIO), TP_SWDIO.TP
SWO: P1.01/2.4B.P$AD22 (P1.00), TP_SWO.TP
VBAT: C37.1, IC1.C2 (BAT); also elsewhere on the board
VBUS: C21.1, C38.1, IC1.A2 (IN), P1.01/2.4B.P$AD2 (VBUS); also elsewhere on the board
VREG: C23.2, C24.2, C39.1, IC1.B2 (SYS), IC2.A1 (EN), IC2.A2 (VIN_1), IC2.A3 (VIN_2), TP_VREG.TP

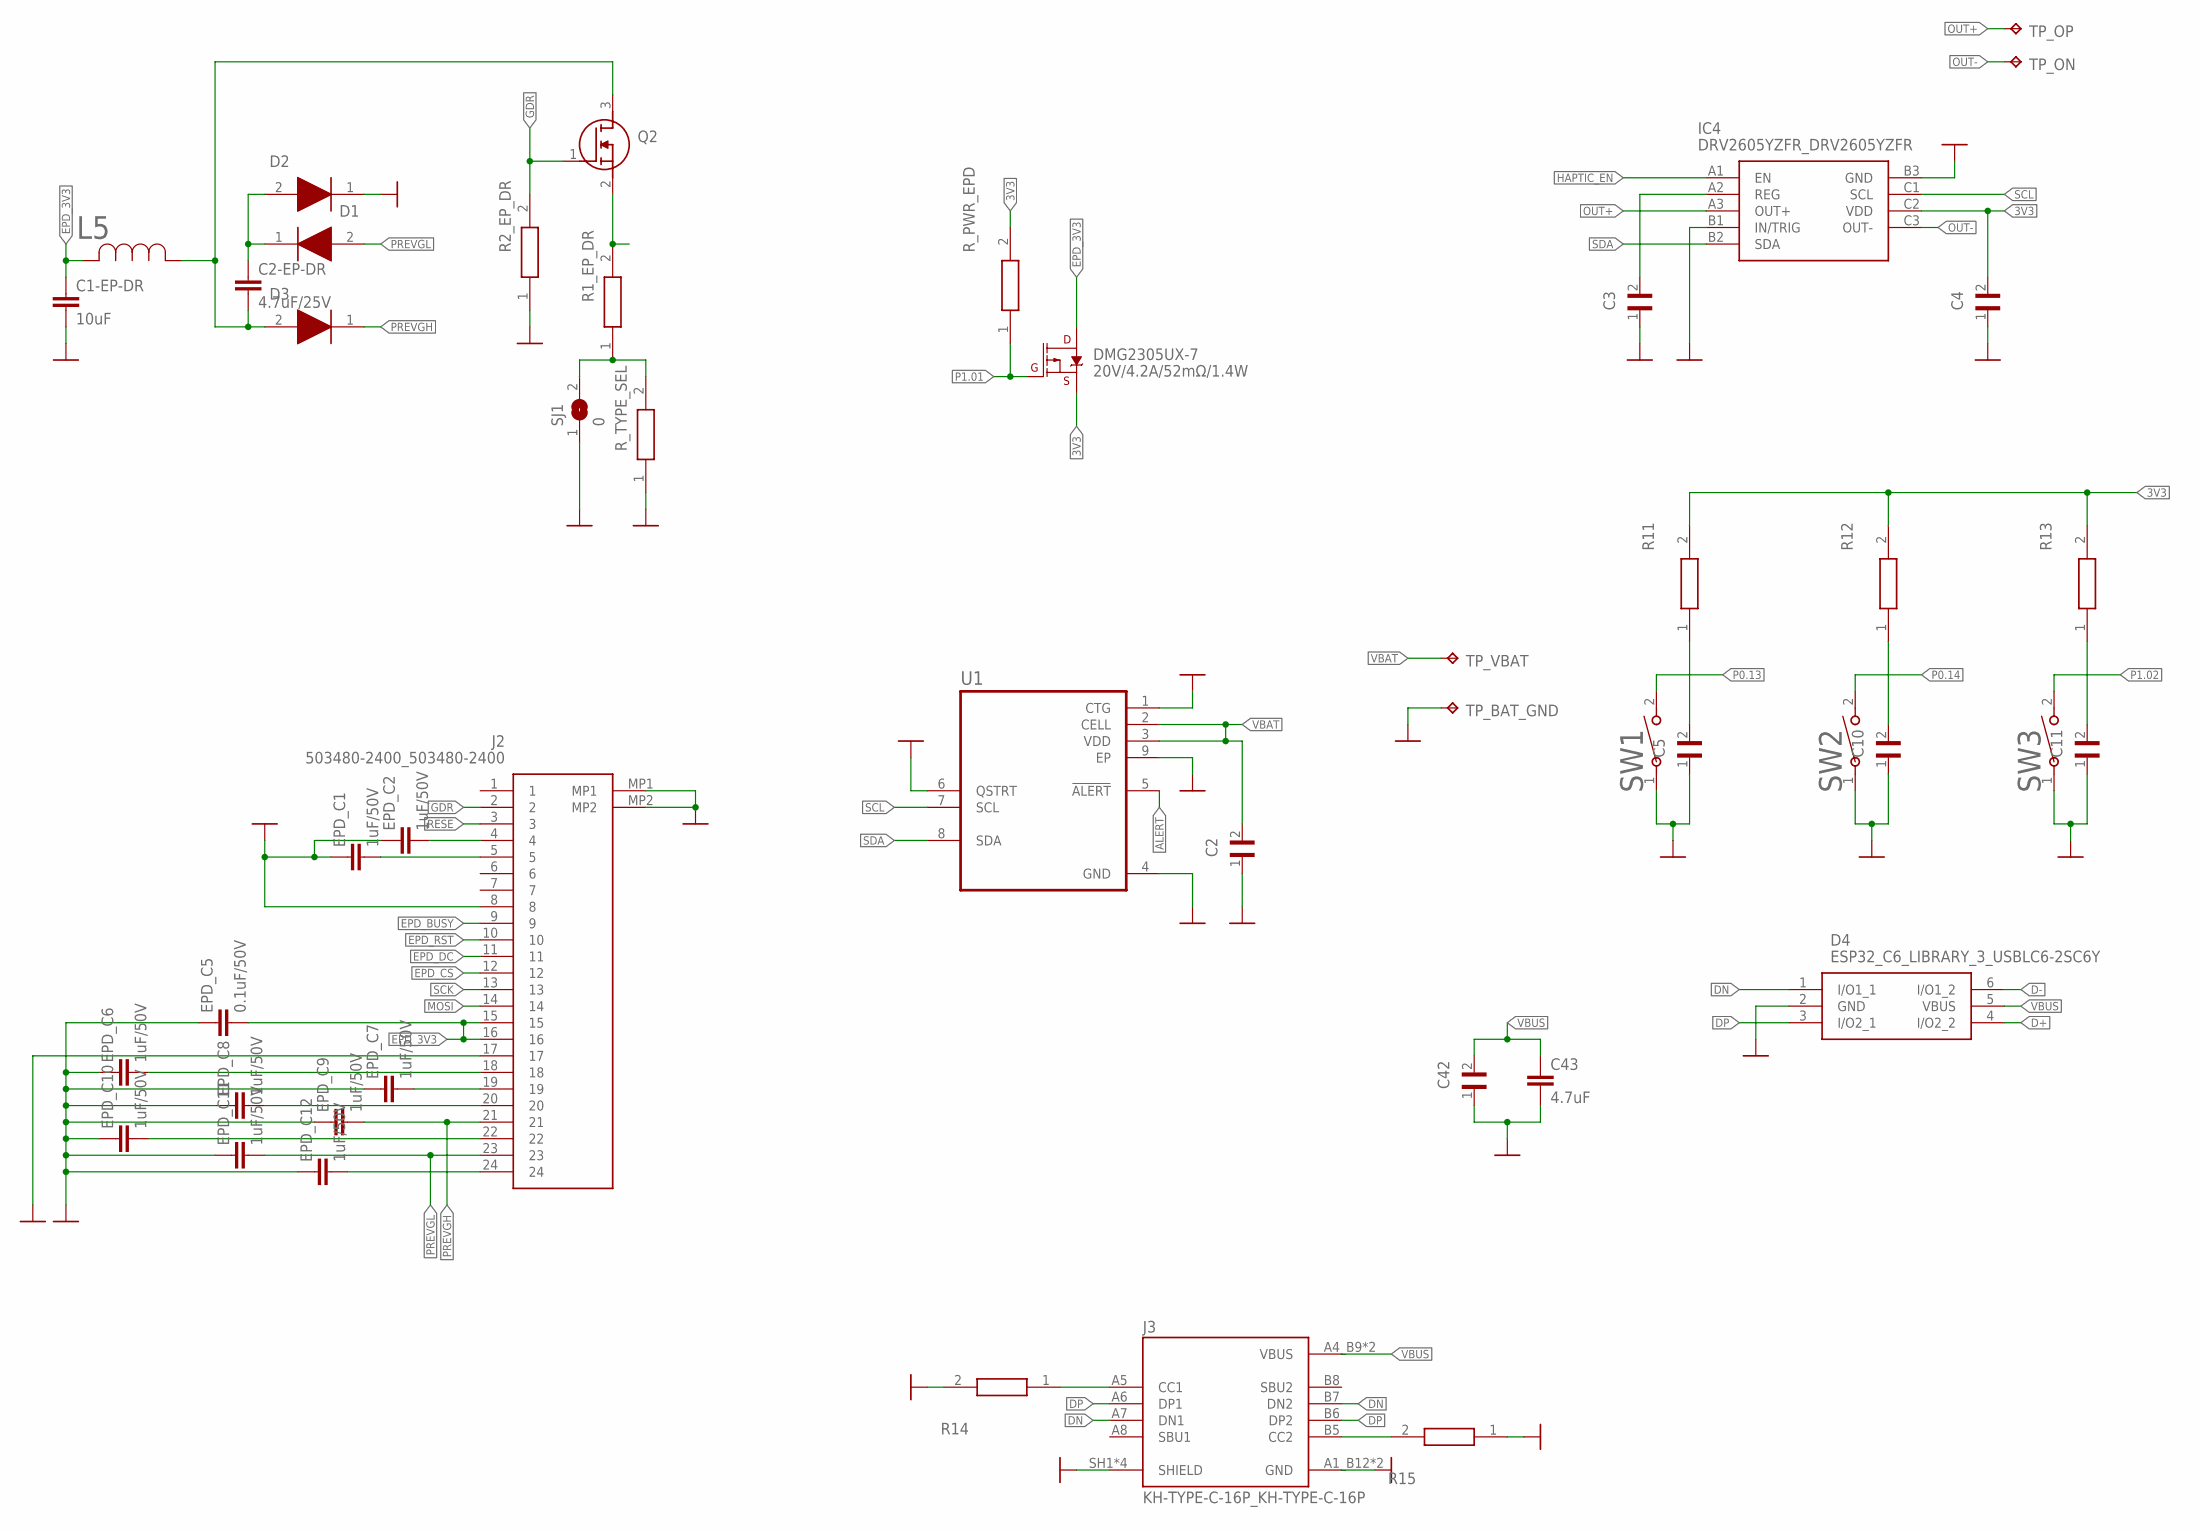
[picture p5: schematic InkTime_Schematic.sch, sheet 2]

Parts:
C1-EP-DR: 10uF; NORDIC_NRF_3_RESC0402_M
C2, C5, C10, C11, C42: GRM011R60J152KE01L_1_GRM011R60J152KE01L; GRM011R60J152KE01L_1_0201
C2-EP-DR: 4.7uF/25V; ESP32_C6_LIBRARY_1_ESP32_WROVER_EAGLE-LTSPICE_C0402
C3: 1uF; GRM011R60J152KE01L_1_0201
C4: 0.1uF; GRM011R60J152KE01L_1_0201
C43: 4.7uF; NORDIC_NRF_3_RESC0402_M
D1, D2, D3: ESP32_C6_LIBRARY_5_MBR0530; ESP32_C6_LIBRARY_5_SOD3716X135N
D4: ESP32_C6_LIBRARY_3_USBLC6-2SC6Y; ESP32_C6_LIBRARY_3_SOT95P280X145-6N
DMG2305UX-7: 20V/4.2A/52mΩ/1.4W; ESP32_C6_LIBRARY_4_ESP32_C6_LIBRARY_4_ESP32_C6_LIBRARY_4_ES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
EPD_C1, EPD_C2, EPD_C6, EPD_C7, EPD_C8, EPD_C9, EPD_C10, EPD_C11, EPD_C12: 1uF/50V; NORDIC_NRF_3_RESC0402_M
EPD_C5: 0.1uF/50V; NORDIC_NRF_3_RESC0402_M
IC4: DRV2605YZFR_DRV2605YZFR; DRV2605YZFR_BGA9C50P3X3_144X144X62
J2: 503480-2400_503480-2400; 503480-2400_5034802400
J3: KH-TYPE-C-16P_KH-TYPE-C-16P; KH-TYPE-C-16P_KINGHELM_KH-TYPE-C-16P
L5: ESP32_C6_LIBRARY_2_744043680IND_4828-WE-TPC_WRE; ESP32_C6_LIBRARY_2_IND_4828-WE-TPC_WRE
Q2: ESP32_C6_LIBRARY_6_SI1308EDL-T1-GE3; ESP32_C6_LIBRARY_6_SOT65P210X110-3N
R1_EP_DR, R2_EP_DR, R11, R12, R13, R14, R15: CPF0201D7K68C1_CPF0201D7K68C1; CPF0201D7K68C1_0201
R_PWR_EPD: CPF0201D7K68C1_CPF0201D7K68C1; CPF0201D7K68C1_0201
R_TYPE_SEL: CPF0201D7K68C1_CPF0201D7K68C1; CPF0201D7K68C1_0201
SJ1: 0; ESP32_C6_LIBRARY_7_JUMPER_SJ
SW1, SW2, SW3: 2025-10-22_07-23-44_LIBRARY_EVP-AKE31ASW_EVP-AKE3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; 2025-10-22_07-23-44_LIBRARY_SW_EVP-AKE31A_PAN
TP_BAT_GND: HECTOR_WATCH_1_TPTP20R; HECTOR_WATCH_1_TP20R
TP_ON: HECTOR_WATCH_1_TPTP20R; HECTOR_WATCH_1_TP20R
TP_OP: HECTOR_WATCH_1_TPTP20R; HECTOR_WATCH_1_TP20R
TP_VBAT: HECTOR_WATCH_1_TPTP20R; HECTOR_WATCH_1_TP20R
U1: ESP32_C6_LIBRARY_MAX17048G+T10; ESP32_C6_LIBRARY_SON50P200X200X80-9N

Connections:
3V3: C4.2, DMG2305UX-7.2 (S), IC4.C2 (VDD), R11.2, R12.2, R13.2, R_PWR_EPD.2; also elsewhere on the board
ALERT: U1.5 (!ALERT); also elsewhere on the board
D+: D4.4 (I/O2_2); also elsewhere on the board
D-: D4.6 (I/O1_2); also elsewhere on the board
DN: D4.1 (I/O1_1), J3.A7 (DN1), J3.B7 (DN2)
DP: D4.3 (I/O2_1), J3.A6 (DP1), J3.B6 (DP2)
EPD_3V3: C1-EP-DR.1, DMG2305UX-7.3 (D), EPD_C5.2, J2.15, J2.16, L5.2
EPD_BUSY: J2.9; also elsewhere on the board
EPD_CS: J2.12; also elsewhere on the board
EPD_DC: J2.11; also elsewhere on the board
EPD_RST: J2.10; also elsewhere on the board
GDR: J2.2, Q2.1 (G), R2_EP_DR.2
GND: C1-EP-DR.2, C2.1, C3.1, C4.1, C5.1, C10.1, C11.1, C42.1, C43.2, D2.1 (K), D4.2 (GND), EPD_C1.1, EPD_C2.1, EPD_C5.1, EPD_C6.1, EPD_C7.1, EPD_C8.1, EPD_C9.1, EPD_C10.1, EPD_C11.1, EPD_C12.1, IC4.B1 (IN/TRIG), IC4.B3 (GND), J2.8, J2.17, J2.MP1, J2.MP2, J3.A1_B12 (GND), J3.A12_B1 (GND), J3.SH1 (SHIELD), J3.SH2 (SHIELD), J3.SH3 (SHIELD), J3.SH4 (SHIELD), R2_EP_DR.1, R14.2, R15.1, R_TYPE_SEL.1, SJ1.1, SW1.1, SW2.1, SW3.1, TP_BAT_GND.TP, U1.1 (CTG), U1.4 (GND), U1.6 (QSTRT), U1.9 (EP); also elsewhere on the board
HAPTIC_EN: IC4.A1 (EN); also elsewhere on the board
MOSI: J2.14; also elsewhere on the board
unnamed: C2-EP-DR.1, D1.1 (K), D2.2 (A)
unnamed: Q2.2 (S), R1_EP_DR.2
unnamed: R1_EP_DR.1, R_TYPE_SEL.2, SJ1.2
unnamed: C2-EP-DR.2, D3.2 (A), L5.1, Q2.3 (D)
unnamed: EPD_C2.2, J2.4
unnamed: EPD_C1.2, J2.5
unnamed: J3.B5 (CC2), R15.2
unnamed: EPD_C7.2, J2.19
unnamed: C5.2, R11.1
unnamed: EPD_C12.2, J2.24
unnamed: EPD_C6.2, J2.18
unnamed: EPD_C8.2, J2.20
unnamed: C10.2, R12.1
unnamed: EPD_C10.2, J2.22
unnamed: C11.2, R13.1
unnamed: J3.A5 (CC1), R14.1
unnamed: C3.2, IC4.A2 (REG)
OUT+: IC4.A3 (OUT+), TP_OP.TP
OUT-: IC4.C3 (OUT-), TP_ON.TP
P0.13: SW1.2; also elsewhere on the board
P0.14: SW2.2; also elsewhere on the board
P1.01: DMG2305UX-7.1 (G), R_PWR_EPD.1; also elsewhere on the board
P1.02: SW3.2; also elsewhere on the board
PREVGH: D3.1 (K), EPD_C9.2, J2.21
PREVGL: D1.2 (A), EPD_C11.2, J2.23
RESE: J2.3
SCK: J2.13; also elsewhere on the board
SCL: IC4.C1 (SCL), U1.7 (SCL); also elsewhere on the board
SDA: IC4.B2 (SDA), U1.8 (SDA); also elsewhere on the board
VBAT: C2.2, TP_VBAT.TP, U1.2 (CELL), U1.3 (VDD); also elsewhere on the board
VBUS: C42.2, C43.1, D4.5 (VBUS), J3.A4_B9 (VBUS), J3.A9_B4 (VBUS); also elsewhere on the board

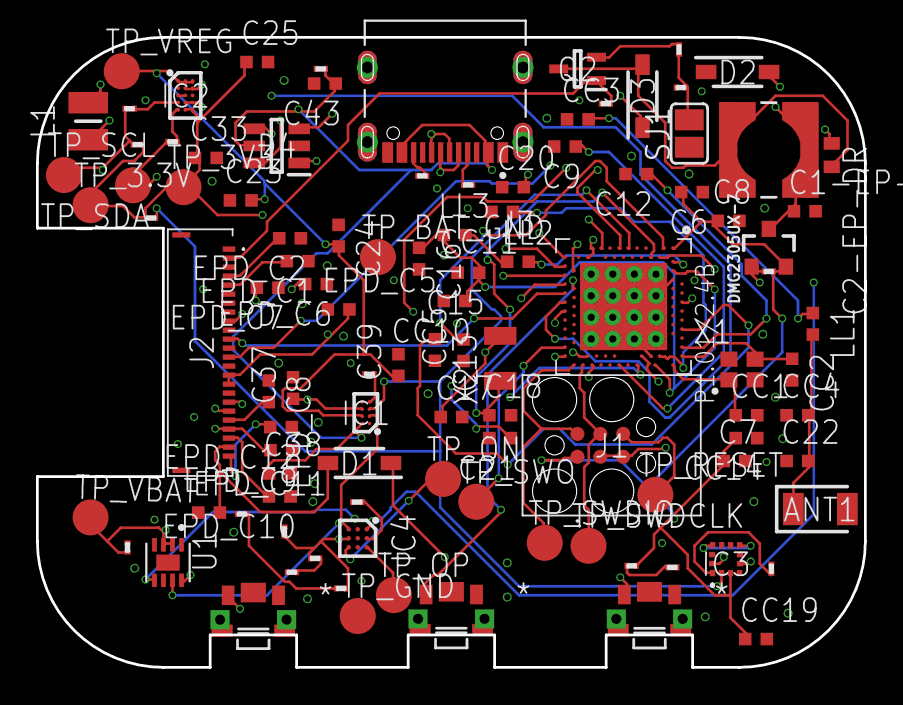
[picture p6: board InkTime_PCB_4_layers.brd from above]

Board: 4 copper layers, 46.0 x 35.0 mm, 105 parts (0 on the bottom side), 74 nets.

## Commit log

2026-04-06 added schematic
    [schematic.sch]
2026-04-06 added pcb
    [pcb.brd]
2026-04-09 added missing project files
    [BillOfMaterials.csv, InkTime_PCB.brd, InkTime_Schematic.sch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]
2026-04-18 Added GND value to GND objects
    [InkTime_Schematic.sch]
2026-04-18 redenumire TP
    [InkTime_Schematic.sch]
2026-04-18 added pcb version with correct copper dimensions and board thickness
    [InkTime_PCB_v2.brd]
2026-04-18 added drill file to gerberfiles
2026-04-18 added 4 layer pcb variant and fixed schematic broken connections
    [InkTime_PCB_4_layers.brd, InkTime_Schematic.sch]

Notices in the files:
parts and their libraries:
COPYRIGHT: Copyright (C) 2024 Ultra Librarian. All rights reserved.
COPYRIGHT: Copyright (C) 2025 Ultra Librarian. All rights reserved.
